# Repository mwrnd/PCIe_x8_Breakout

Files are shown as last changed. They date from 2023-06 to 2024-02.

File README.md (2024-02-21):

# PCIe_x8_Breakout

PCIe x8 Signal Breakout to [U.FL/UMCC Connectors](https://en.wikipedia.org/wiki/Hirose_U.FL).

[PCIEX1-SMA](https://github.com/teknoman117/PCIEX1-SMA/tree/f63db3cca1db83d9b58e01254d8104f65855b762) is a similar project that is PCIe x1 and uses SMA connectors.

The board requires up to 34 [U.FL/UMCC Surface Mount Receptacles](https://www.digikey.com/en/products/detail/te-connectivity-amp-connectors/2337019-1/9974052) and a 16-Pin 2.54mm [Header](https://www.digikey.com/en/products/detail/sullins-connector-solutions/PREC008DAAN-RC/2774886) or [Socket](https://www.digikey.com/en/products/detail/adam-tech/RS2-16-G/9832058).

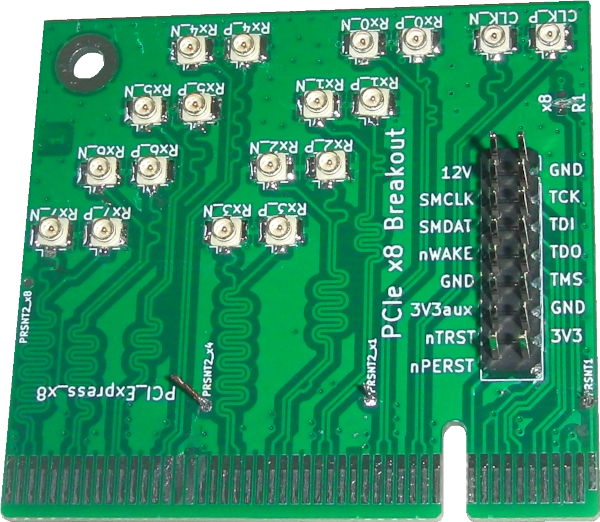
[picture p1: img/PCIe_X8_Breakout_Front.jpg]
PCIe x8 Breakout PCB


Related Projects: [OpenCAPI_Breakout](https://github.com/mwrnd/OpenCAPI_Breakout), [OpenCAPI-to-PCIe](https://github.com/mwrnd/OpenCAPI-to-PCIe), [OpenCAPI-to-PCIe_x4_Host_and_Endpoint](https://github.com/mwrnd/OpenCAPI-to-PCIe_x4_Host_and_Endpoint)

# Testing and Use Example

The board is currently being used along with an [OpenCAPI_Breakout](https://github.com/mwrnd/OpenCAPI_Breakout) board to test [OpenCAPI-to-PCIe](https://github.com/mwrnd/innova2_experiments/tree/main/xdma_opencapi) on the [Innova-2 SmartNIC](https://www.nvidia.com/en-us/networking/ethernet/innova-2-flex/). PCIe 3.0 x4 at 8.0GT/s is currently working. Standard [0.1" M-F Jumpers](https://www.digikey.com/en/products/detail/adafruit-industries-llc/1954/6827087) are used for the PCIe Reset Signal (*nPERST*) and its GND.

With cables shorter than 4"~=100mm the [adapters work](https://github.com/mwrnd/innova2_experiments/tree/main/xdma_opencapi). Note the [RX U.FL-to-U.FL cables](https://www.digikey.com/en/products/detail/te-connectivity-amp-connectors/2118651-6/11205742) are all the same length as each other and likewise all [TX cables](https://www.digikey.com/en/products/detail/te-connectivity-amp-connectors/2015698-2/1249186) are the same length but RX and TX are different lengths as that is what I had access to. RX on the PCIe board connects to RX on the OpenCAPI board as it uses the OpenCAPI Host pinout. 

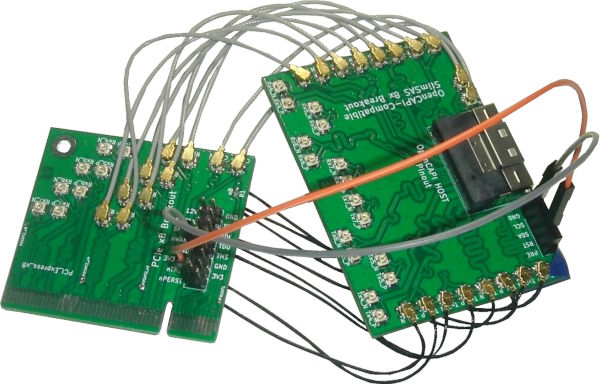
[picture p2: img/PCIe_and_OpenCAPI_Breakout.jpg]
PCIe x8 Breakout and OpenCAPI Breakout


PCIe x4 In-system:

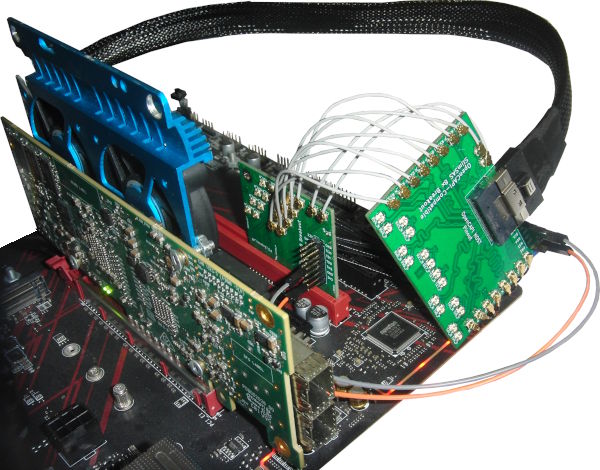
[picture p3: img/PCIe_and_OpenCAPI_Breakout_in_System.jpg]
PCIe x8 Breakout and OpenCAPI Breakout In System


However, using 250mm IPEX cables the adapters fail for PCIe x8:

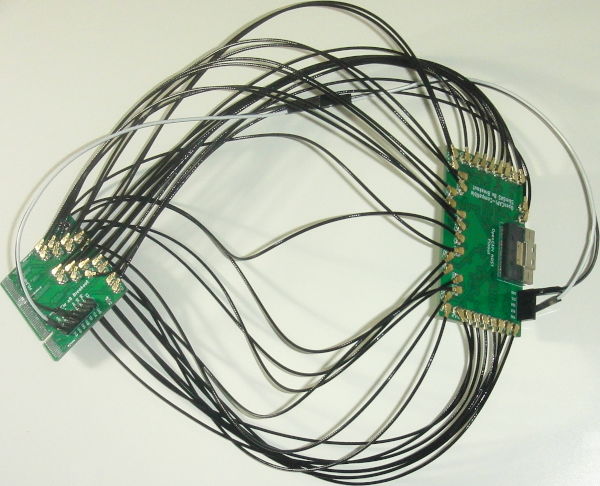
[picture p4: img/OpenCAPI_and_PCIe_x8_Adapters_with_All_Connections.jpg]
PCIe x8 Breakout and OpenCAPI Breakout All Connections


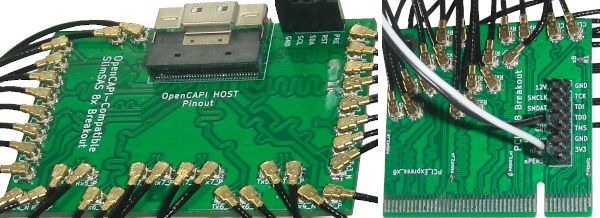
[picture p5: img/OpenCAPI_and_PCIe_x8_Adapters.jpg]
Adapters Close-up


PCIe x8 In-system:

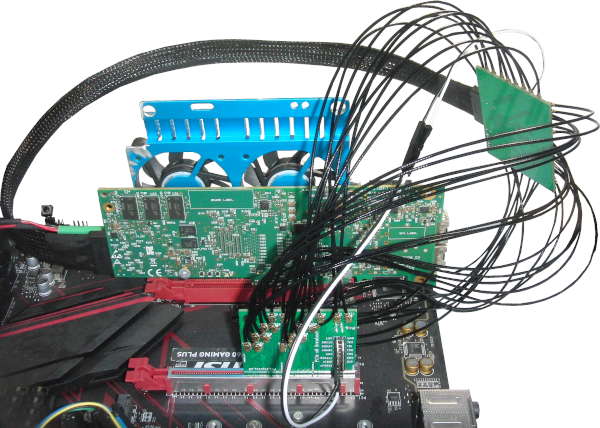
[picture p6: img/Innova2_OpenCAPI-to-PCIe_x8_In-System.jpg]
OpenCAPI to PCIe x8 In-System


# PCB Layout

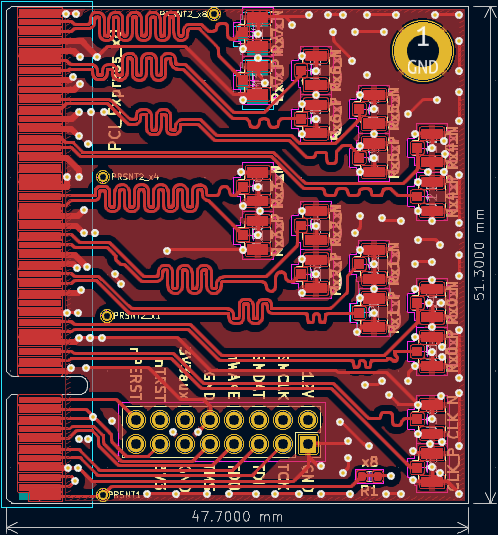
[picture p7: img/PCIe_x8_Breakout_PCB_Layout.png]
PCIe x8 Breakout PCB Layout


All signals are length-matched to within 1mm both inter-pair and intra-pair.

Resistor footprint R1 connects `PRSNT1` to `PRSNT2_x8`. The R1 trace can be cut and `PRSNT1` can be connected to a different `PRSNT2` to reduce the [PCIe lane width](https://en.wikipedia.org/wiki/PCI_Express#Lane).

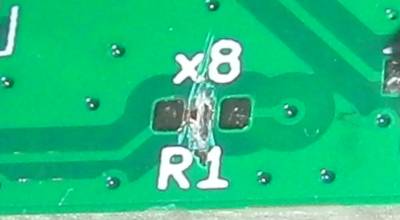
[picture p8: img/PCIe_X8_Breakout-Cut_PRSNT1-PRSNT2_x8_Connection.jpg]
R1 Connects PRSNT1 to PRSNT2_x8


Wire jumpers can then be used to connect `PRSNT1` to any of the `PRSNT2`.

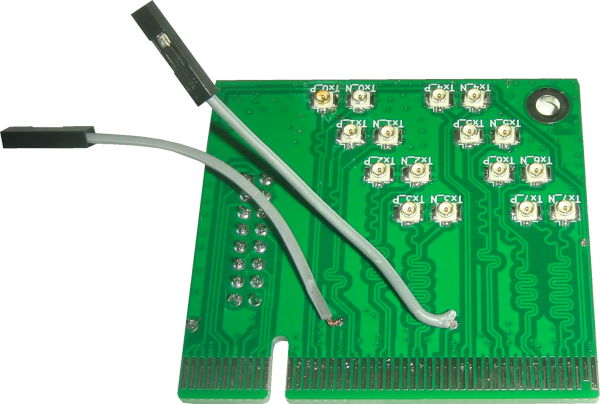
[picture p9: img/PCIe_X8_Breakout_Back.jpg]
PRSNT1 and PRSNT2 Jumpers


# Schematic

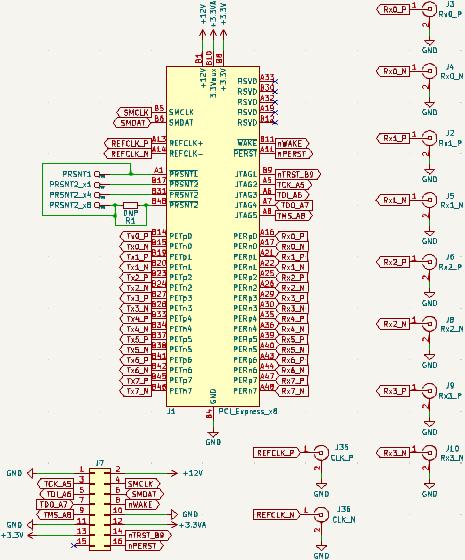
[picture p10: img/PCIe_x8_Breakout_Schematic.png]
PCIe x8 Breakout Schematic


# PCB Layer Stackup

4-Layer PCB stackup taken from [JLCPCB](https://jlcpcb.com/capabilities/pcb-capabilities).

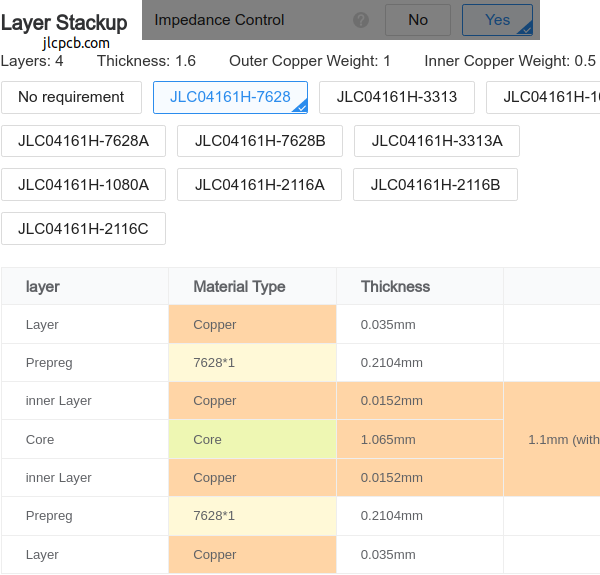
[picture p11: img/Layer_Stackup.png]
PCB Layer Stackup


Differential Impedance parameters were calculated using the [DigiKey Online Calculator](https://www.digikey.com/en/resources/conversion-calculators/conversion-calculator-pcb-trace-impedance).

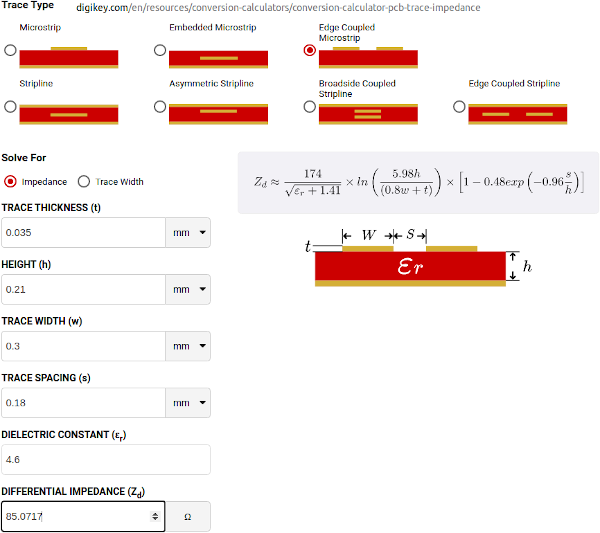
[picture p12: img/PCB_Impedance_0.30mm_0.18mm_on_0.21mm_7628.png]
PCB Differential Impedance Calculation


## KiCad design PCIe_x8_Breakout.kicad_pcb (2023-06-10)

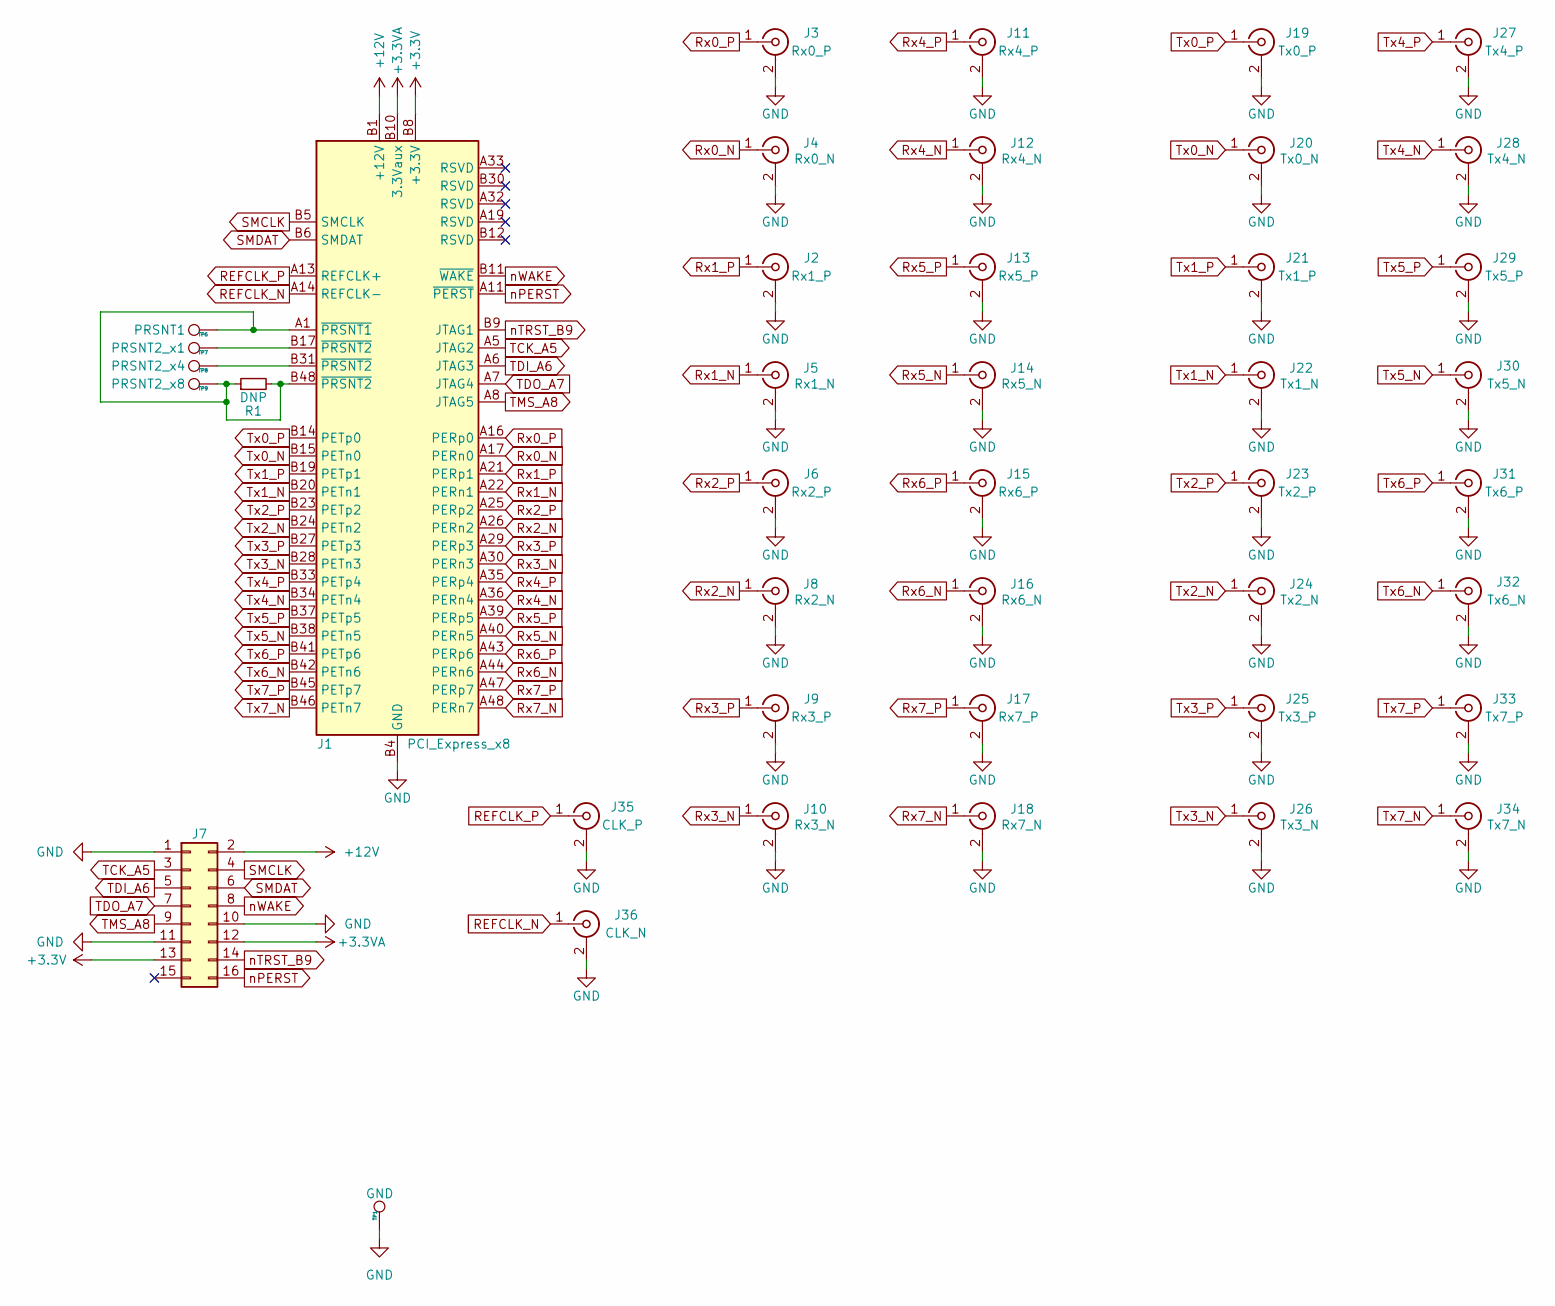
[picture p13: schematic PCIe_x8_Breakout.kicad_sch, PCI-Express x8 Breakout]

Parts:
J1: PCI_Express_x8; BUS_PCIexpress_x8
J2: Rx1_P; U.FL_Hirose_w_Label
J3: Rx0_P; U.FL_Hirose_w_Label
J4: Rx0_N; U.FL_Hirose_w_Label
J5: Rx1_N; U.FL_Hirose_w_Label
J6: Rx2_P; U.FL_Hirose_w_Label
J7: Conn_02x08_Odd_Even; PinSocket_2x08_P2.54mm_Vertical
J8: Rx2_N; U.FL_Hirose_w_Label
J9: Rx3_P; U.FL_Hirose_w_Label
J10: Rx3_N; U.FL_Hirose_w_Label
J11: Rx4_P; U.FL_Hirose_w_Label
J12: Rx4_N; U.FL_Hirose_w_Label
J13: Rx5_P; U.FL_Hirose_w_Label
J14: Rx5_N; U.FL_Hirose_w_Label
J15: Rx6_P; U.FL_Hirose_w_Label
J16: Rx6_N; U.FL_Hirose_w_Label
J17: Rx7_P; U.FL_Hirose_w_Label
J18: Rx7_N; U.FL_Hirose_w_Label
J19: Tx0_P; U.FL_Hirose_w_Label
J20: Tx0_N; U.FL_Hirose_w_Label
J21: Tx1_P; U.FL_Hirose_w_Label
J22: Tx1_N; U.FL_Hirose_w_Label
J23: Tx2_P; U.FL_Hirose_w_Label
J24: Tx2_N; U.FL_Hirose_w_Label
J25: Tx3_P; U.FL_Hirose_w_Label
J26: Tx3_N; U.FL_Hirose_w_Label
J27: Tx4_P; U.FL_Hirose_w_Label
J28: Tx4_N; U.FL_Hirose_w_Label
J29: Tx5_P; U.FL_Hirose_w_Label
J30: Tx5_N; U.FL_Hirose_w_Label
J31: Tx6_P; U.FL_Hirose_w_Label
J32: Tx6_N; U.FL_Hirose_w_Label
J33: Tx7_P; U.FL_Hirose_w_Label
J34: Tx7_N; U.FL_Hirose_w_Label
J35: CLK_P; U.FL_Hirose_w_Label
J36: CLK_N; U.FL_Hirose_w_Label
R1: DNP; R_0603_1608Metric
TP1: GND; PinSocket_1x01_P2.54mm_Vertical
TP6: PRSNT1; PinHeader_1x01_P1.00mm_Vertical
TP7: PRSNT2_x1; PinHeader_1x01_P1.00mm_Vertical
TP8: PRSNT2_x4; PinHeader_1x01_P1.00mm_Vertical
TP9: PRSNT2_x8; PinHeader_1x01_P1.00mm_Vertical

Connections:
+3.3V: J1.A9 (+3.3V), J1.A10 (+3.3V), J1.B8 (+3.3V), J7.13
+3.3VA: J1.B10 (3.3Vaux), J7.12
+12V: J1.A2 (+12V), J1.A3 (+12V), J1.B1 (+12V), J1.B2 (+12V), J1.B3 (+12V), J7.2
GND: J1.A4 (GND), J1.A12 (GND), J1.A15 (GND), J1.A18 (GND), J1.A20 (GND), J1.A23 (GND), J1.A24 (GND), J1.A27 (GND), J1.A28 (GND), J1.A31 (GND), J1.A34 (GND), J1.A37 (GND), J1.A38 (GND), J1.A41 (GND), J1.A42 (GND), J1.A45 (GND), J1.A46 (GND), J1.A49 (GND), J1.B4 (GND), J1.B7 (GND), J1.B13 (GND), J1.B16 (GND), J1.B18 (GND), J1.B21 (GND), J1.B22 (GND), J1.B25 (GND), J1.B26 (GND), J1.B29 (GND), J1.B32 (GND), J1.B35 (GND), J1.B36 (GND), J1.B39 (GND), J1.B40 (GND), J1.B43 (GND), J1.B44 (GND), J1.B47 (GND), J1.B49 (GND), J2.2 (Ext), J3.2 (Ext), J4.2 (Ext), J5.2 (Ext), J6.2 (Ext), J7.1, J7.10, J7.11, J8.2 (Ext), J9.2 (Ext), J10.2 (Ext), J11.2 (Ext), J12.2 (Ext), J13.2 (Ext), J14.2 (Ext), J15.2 (Ext), J16.2 (Ext), J17.2 (Ext), J18.2 (Ext), J19.2 (Ext), J20.2 (Ext), J21.2 (Ext), J22.2 (Ext), J23.2 (Ext), J24.2 (Ext), J25.2 (Ext), J26.2 (Ext), J27.2 (Ext), J28.2 (Ext), J29.2 (Ext), J30.2 (Ext), J31.2 (Ext), J32.2 (Ext), J33.2 (Ext), J34.2 (Ext), J35.2 (Ext), J36.2 (Ext), TP1.1
unnamed: J1.A1 (~PRSNT1), J1.B48 (~PRSNT2), R1.1, R1.2, TP6.1, TP9.1
unnamed: J1.B17 (~PRSNT2), TP7.1
unnamed: J1.B31 (~PRSNT2), TP8.1
REFCLK_N: J1.A14 (REFCLK-), J36.1 (In)
REFCLK_P: J1.A13 (REFCLK+), J35.1 (In)
Rx0_N: J1.A17 (PERn0), J4.1 (In)
Rx0_P: J1.A16 (PERp0), J3.1 (In)
Rx1_N: J1.A22 (PERn1), J5.1 (In)
Rx1_P: J1.A21 (PERp1), J2.1 (In)
Rx2_N: J1.A26 (PERn2), J8.1 (In)
Rx2_P: J1.A25 (PERp2), J6.1 (In)
Rx3_N: J1.A30 (PERn3), J10.1 (In)
Rx3_P: J1.A29 (PERp3), J9.1 (In)
Rx4_N: J1.A36 (PERn4), J12.1 (In)
Rx4_P: J1.A35 (PERp4), J11.1 (In)
Rx5_N: J1.A40 (PERn5), J14.1 (In)
Rx5_P: J1.A39 (PERp5), J13.1 (In)
Rx6_N: J1.A44 (PERn6), J16.1 (In)
Rx6_P: J1.A43 (PERp6), J15.1 (In)
Rx7_N: J1.A48 (PERn7), J18.1 (In)
Rx7_P: J1.A47 (PERp7), J17.1 (In)
SMCLK: J1.B5 (SMCLK), J7.4
SMDAT: J1.B6 (SMDAT), J7.6
TCK_A5: J1.A5 (JTAG2), J7.3
TDI_A6: J1.A6 (JTAG3), J7.5
TDO_A7: J1.A7 (JTAG4), J7.7
TMS_A8: J1.A8 (JTAG5), J7.9
Tx0_N: J1.B15 (PETn0), J20.1 (In)
Tx0_P: J1.B14 (PETp0), J19.1 (In)
Tx1_N: J1.B20 (PETn1), J22.1 (In)
Tx1_P: J1.B19 (PETp1), J21.1 (In)
Tx2_N: J1.B24 (PETn2), J24.1 (In)
Tx2_P: J1.B23 (PETp2), J23.1 (In)
Tx3_N: J1.B28 (PETn3), J26.1 (In)
Tx3_P: J1.B27 (PETp3), J25.1 (In)
Tx4_N: J1.B34 (PETn4), J28.1 (In)
Tx4_P: J1.B33 (PETp4), J27.1 (In)
Tx5_N: J1.B38 (PETn5), J30.1 (In)
Tx5_P: J1.B37 (PETp5), J29.1 (In)
Tx6_N: J1.B42 (PETn6), J32.1 (In)
Tx6_P: J1.B41 (PETp6), J31.1 (In)
Tx7_N: J1.B46 (PETn7), J34.1 (In)
Tx7_P: J1.B45 (PETp7), J33.1 (In)
nPERST: J1.A11 (~PERST), J7.16
nTRST_B9: J1.B9 (JTAG1), J7.14
nWAKE: J1.B11 (~WAKE), J7.8

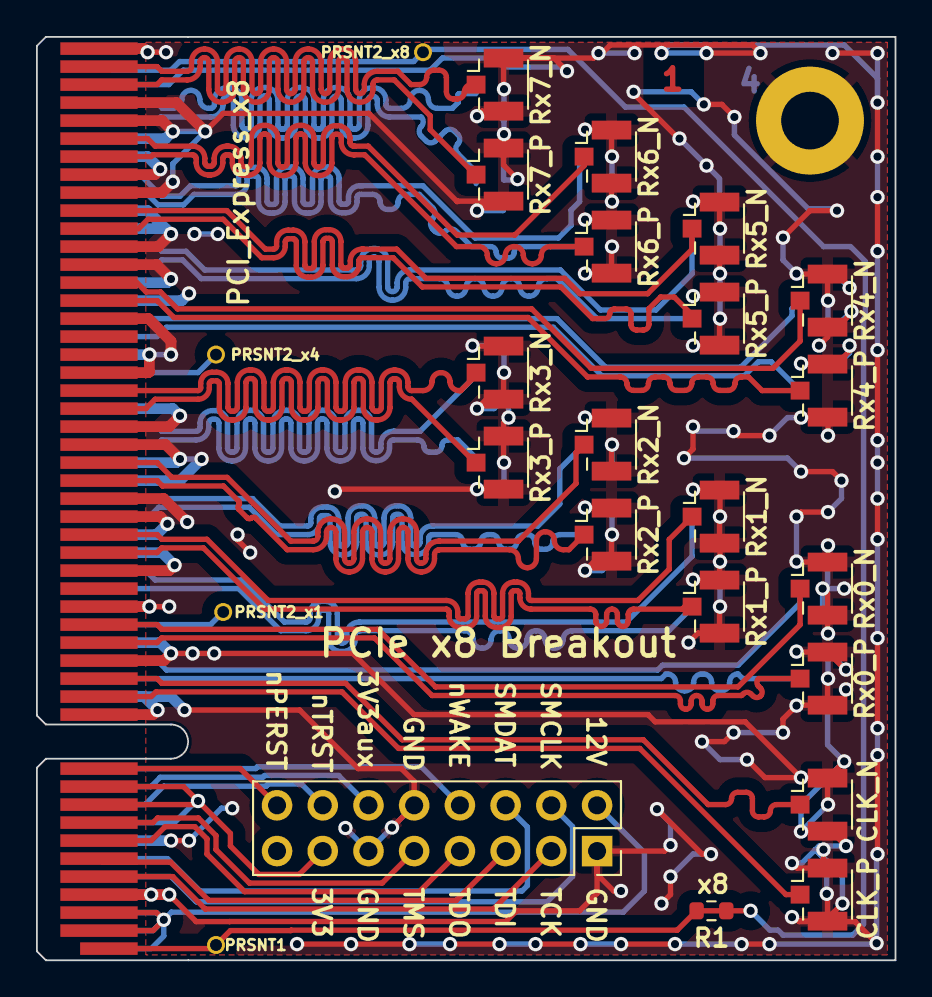
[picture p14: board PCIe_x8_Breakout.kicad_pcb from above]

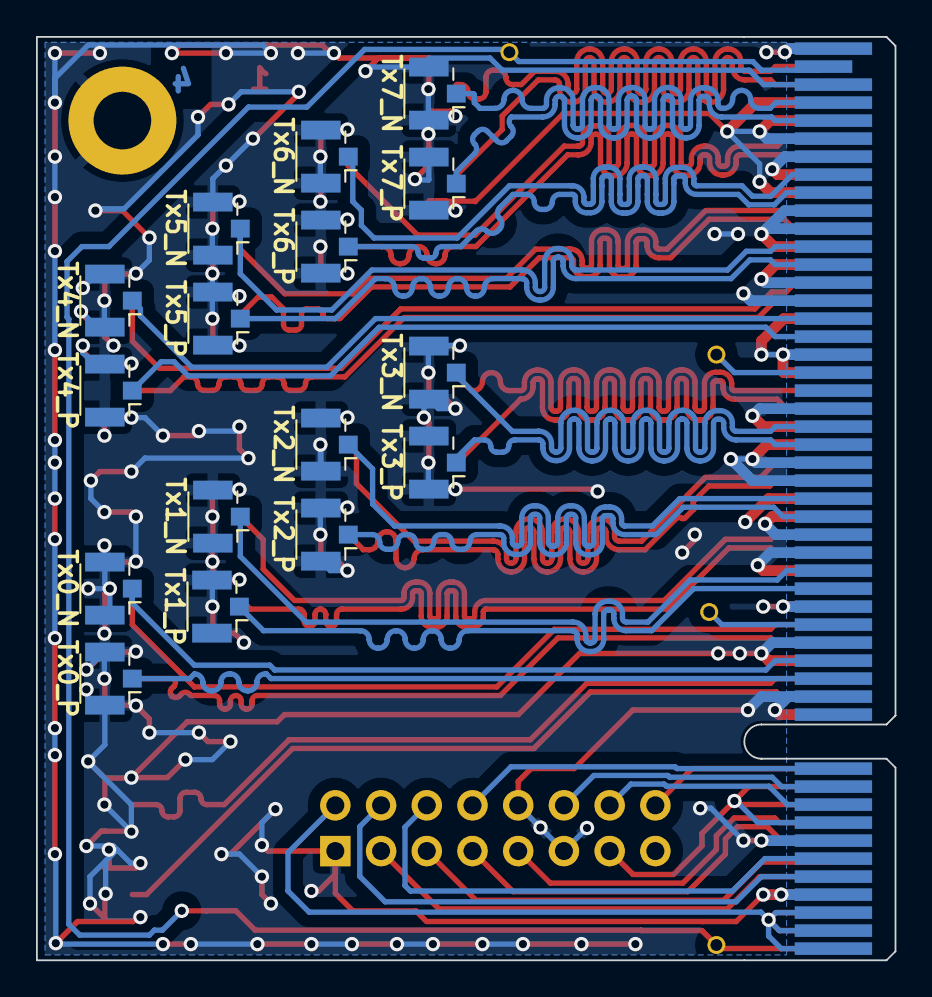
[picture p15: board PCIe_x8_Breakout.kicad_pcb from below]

Board: 4 copper layers, 47.7 x 51.3 mm, 42 parts (17 on the bottom side), 50 nets.
